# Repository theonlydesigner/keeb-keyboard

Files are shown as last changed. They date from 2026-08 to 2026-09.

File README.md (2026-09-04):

# KYPS75 (because my wallet needed to suffer)

welcome to the KYPS75 repository. this is a scratch-built 75% mechanical keyboard featuring dual rotary encoders and an OLED display [because why have one knob when you can have two?]. i originally designed this after realizing my 60% board was actively sabotaging my daily workflow [turns out arrow keys are actually useful, who knew].

## Features
* 75% exploded layout [so you don't accidentally mash the wrong modifiers while panic-typing]
* dual EC11 rotary encoders [master volume on the left, brush size/timeline scrub on the right]
* 0.91" I2C OLED display [mostly just to show off custom graphics]
* custom 3D-printed enclosure [designed to barely fit the USB-C port]
* QMK/VIA compatible [eventually, whenever i finish fighting the firmware]

## Images of my Build
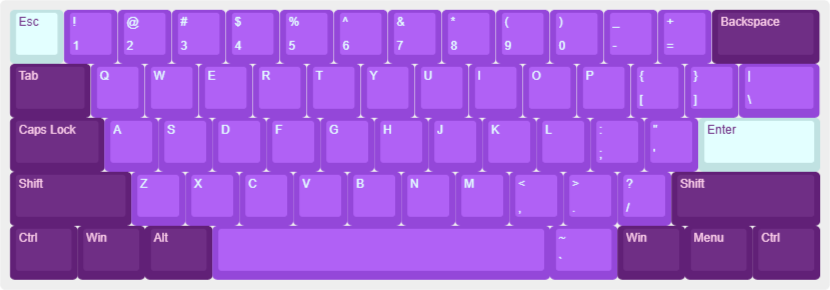
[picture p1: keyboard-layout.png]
layout planning diagram

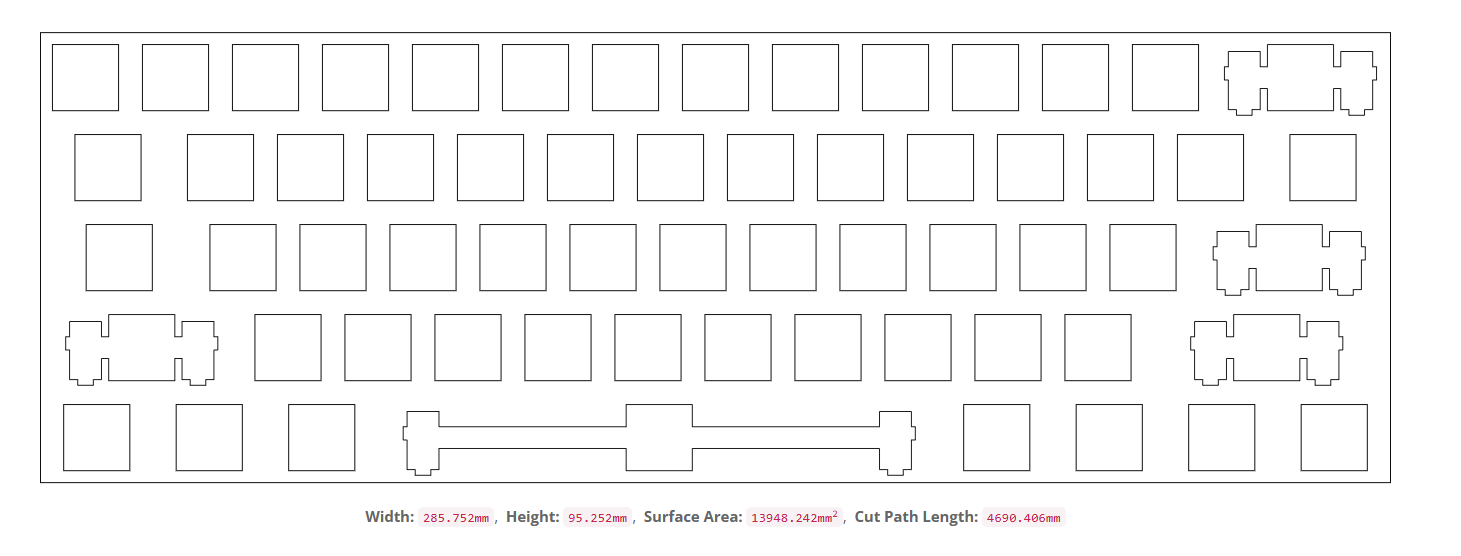
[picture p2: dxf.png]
dxf

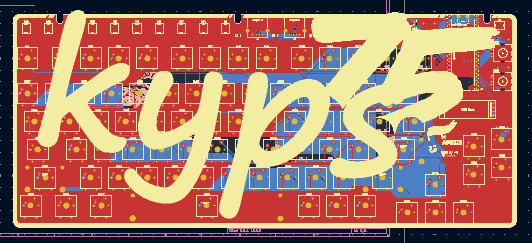
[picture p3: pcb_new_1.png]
pcb_1

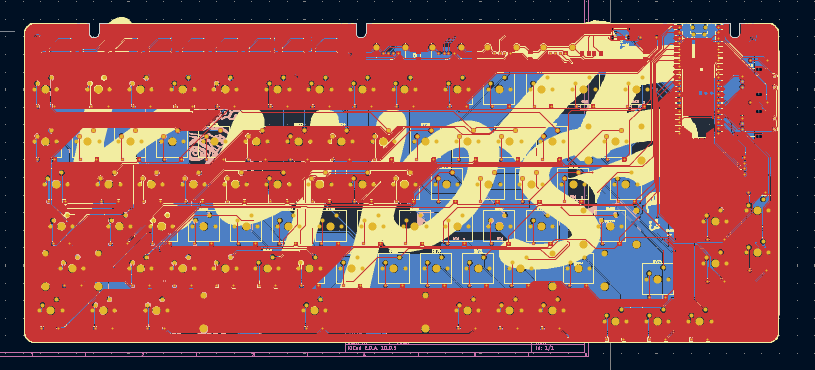
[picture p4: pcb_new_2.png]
pcb_2

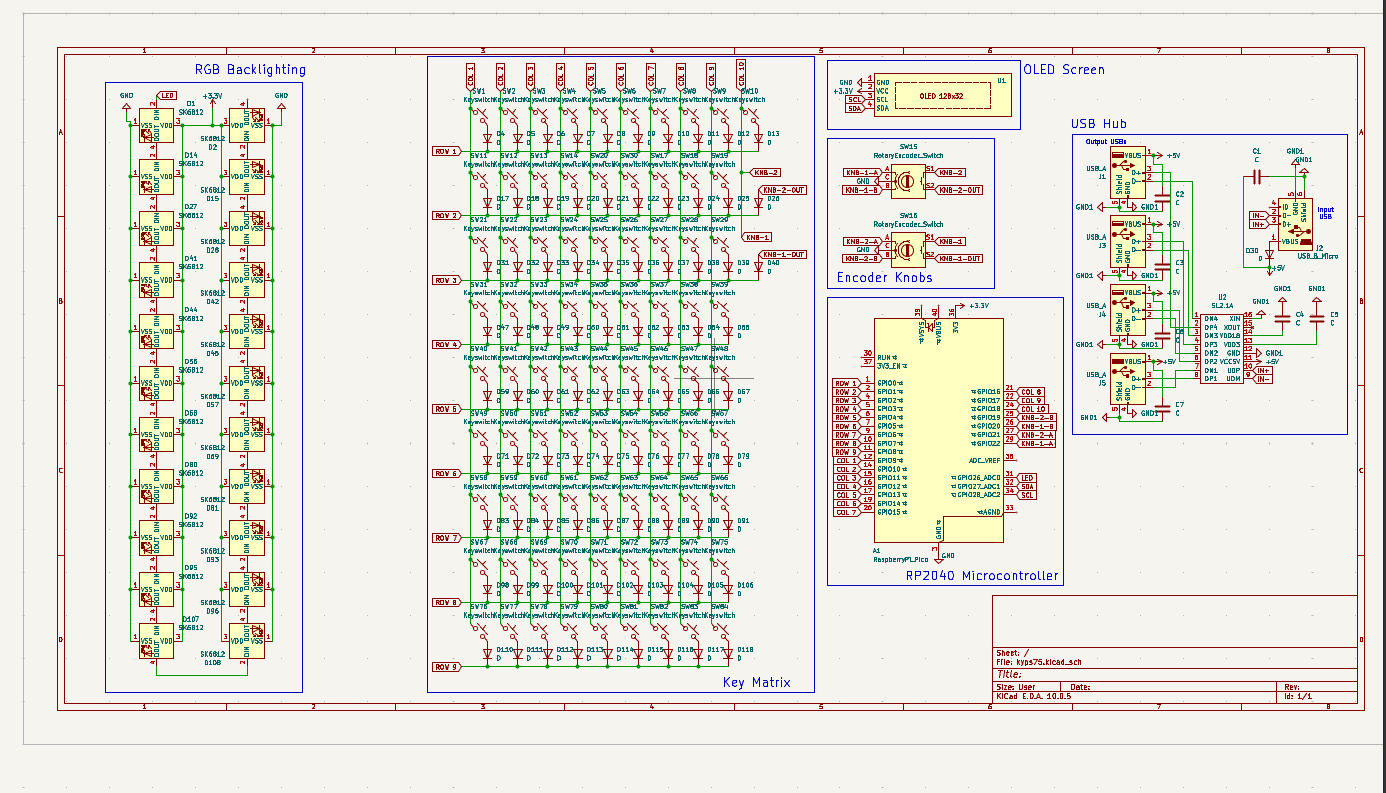
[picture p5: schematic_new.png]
schematic

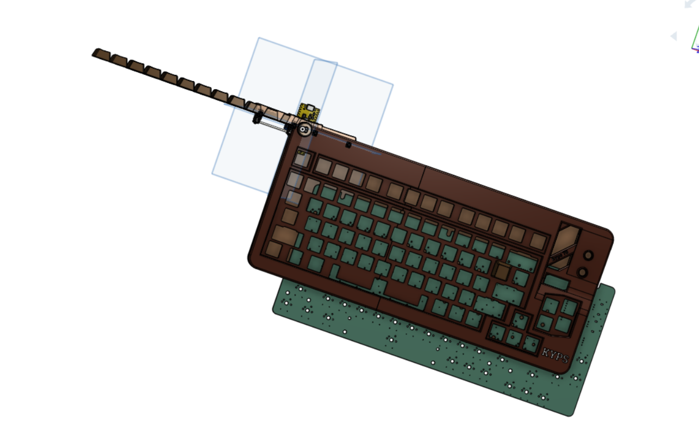
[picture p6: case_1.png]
case_1

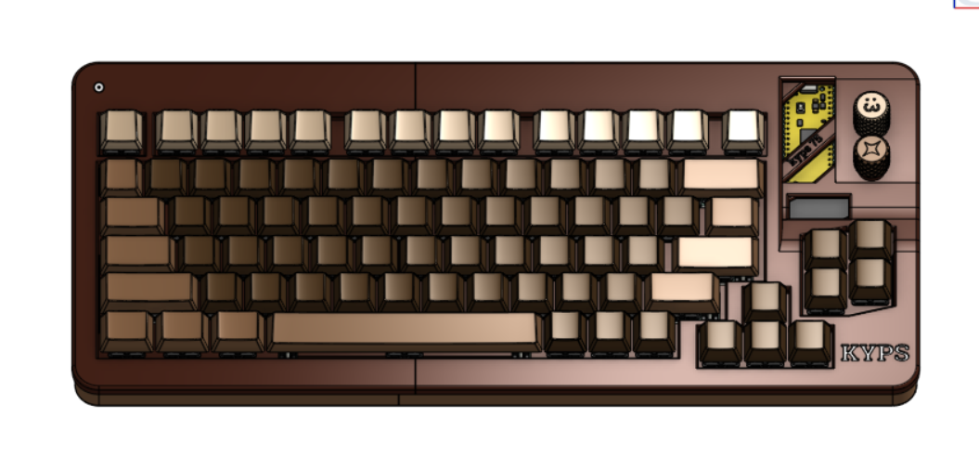
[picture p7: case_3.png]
case_2


## Bill of Materials (BOM)

| Component | Description / Spec | Quantity | Estimated Cost ($) |
| :--- | :--- | :--- | :--- |
| Custom PCB | 75% Layout Scratch-Built PCB | 1 | $15.00 |
| 3D Case | Custom Printed Case (PLA) | 1 | $10.00 |
| Mechanical Switches | MX-Style Mechanical Switches | 82 | $18.00 |
| Rotary Encoders | EC11 Rotary Encoders with Push Switch | 2 | $2.50 |
| OLED Display | 0.91" 128x32 I2C OLED Module | 1 | $3.00 |
| Diodes & SMD | 1N4148 Diodes & SMD Resistors/Caps | 1 Set | $3.50 |
| Keycaps | OEM Profile Keycap Set | 1 | $12.00 |
| **Total** | | | **~$54.00** |

## How to Assemble

1. **PCB SMT Component Soldering:** Solder all surface-mount components (diodes, resistors, capacitors, OLED headers, rotary encoder pins, and controller MCU/sockets) onto the custom PCB.
2. **Switch Placement & Soldering:** Push mechanical switches into the top plate and align switch pins with the PCB socket pads. Solder all switch pins and rotary encoders firmly to the board.
3. **Display & Hardware Installation:** Solder the OLED module onto its header pins and mount the rotary encoder knobs onto the D-shafts.
4. **Case Integration:** Insert the switch/PCB assembly into the 3D-printed bottom housing. Secure it using M2/M3 screws through the mounting tabs.
5. **Keycaps & Finishing:** Press the keycaps onto the switch stems, install rubber feet at the bottom of the case, and plug in the USB-C cable for testing.

(For reviewers- yeah! the assembly is partly written by AI because I had no idea what put into it. but take note,only partly not fully) 

## Known Issues

* **Firmware Pending:** Custom firmware layout is still undergoing final keymapping configuration and key matrix debouncing tweaks. [turns out hardware debouncing is a headache]
* **Tight Case Tolerances:** The 3D-printed case fitment around the USB-C cutout is extremely tight and requires slight filing or precise printer calibration. [sandpaper is your friend]
* **Trace Clearance:** Signal lines near the second rotary encoder required tight routing tolerances; ensure clean soldering to avoid bridging.

## Credits

* **Software & Tools:** [KiCad](https://www.kicad.org/) (PCB & Schematic design), [Keyboard Layout Editor](http://www.keyboard-layout-editor.com/) (Layout concepting), and [SwillKb Plate Builder](http://builder.swillkb.com/) (Plate outline generation).
* **Collaborators:** Special thanks to my two friends for assisting with the 3D enclosure modeling and reviewing the electrical layout logic. [i definitely would have shorted the board and started a fire without them]

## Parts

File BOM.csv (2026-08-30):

Parts | Quantity | Purpose | Price | Total Cost(Including Shipping) | Links
PCB | 1 | Holds components and wires | 82 | 85 | https://cart.jlcpcb.com/quote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
Cherry MX Switches | 82 | Well they press and actually click | 33.05 | 33.05 | https://kprepublic.com/products/cherry-mx-hyperglide-switch-black-switch-for-gaming-mechanical-keyboard-60g-5pin-linear-switch-mx1a-11nw-1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
EC11 Rotatory Encoders | 2 | Turn to change things, macros | 0.97 | 1.6 | https://www.flyrobo.in/ec11-rotary-encoder-with-switch-digital-potentiometer-20mm
SK6812 LEDs 5050 | 22 | To light the keyboard up | 0.87 | 0.87 | https://www.flyrobo.in/5050-red-green-blue-rgb-smd-led?search=SK6812%20LEDs%205050&description=true
0.91 OLED Display | 1 | To display graphics and information | 2.26 | 2.26 | https://www.flyrobo.in/0.91-inch-128-32-oled-display-module-with-i2c-iic-serial-interface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
Raspberry Pi Pico | 1 | Main microcontroller | 7 | 7 | https://jlcpcb.com/parts/componentSearch?searchTxt=Raspberry%20Pi%20Pico
1N4148 Diodes | 85 | Organises rows and columns for microcontroller | Included w/ PCB |  | https://www.flyrobo.in/1n4148-switching-diode-standard-75v-150ma-through-hole
USB A Female Connectors | 5 | Connectors for built in USB-hub | 0.31 | 0.31 | https://www.flyrobo.in/usb-female-90-usb-socket?search=USB%20A%20Female%20Connectors&description=true
Capacitors | 7 | Required for USB hub circuit | 0.1 | 0.1 | https://robu.in/product/grm033r60j104ke19j-murata-electronics-6-3v-100nf-x5r-%c2%b110-0201-multilayer-ceramic-capacitors-mlcc-smd-smt-rohs/
SL2.1A IC | 1 | IC used for USB hub | Included w/ PCB |  | https://jlcpcb.com/partdetail/CoreChips-SL21A/C6798314
6.00u Stabilizers | 1 | Stabilizes the space bar | 21.8 | 21.8 | https://kprepublic.com/products/owlab-stabilizer-v3-pcb-screw-in-stabilizers-for-custom-mechanical-keyboard-kit-2u-6-25u-2x-6-25x-beige-black-pink-purple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
2.00u Stabilizers | 4 | Stabilizes both shift keys, enter, and backspace | Included w/ above
75% Keycaps | 1 Set | Covers keyswitches | 24.15 | 24.15 | https://curiositycaps.in/products/adventurer-1-7mm-thick-pbt-keycaps
Rotary Encoder Knobs | 2 | Covers the encoders | 0 | 0 | 3D print as it is cheaper
#8-32 1/2" Screws | 6 | Assembles the case and plate | 0 | 0 | 3D print as it is cheaper
Micro USB Female Connector | 1 | Input USB for USB hub | 0.03 | 0.03 | https://robu.in/product/micro-usb-type-b-female-5-pin-through-hole-connector/
3D Print(Case, Srews, Knobs) |  | Holds the PCB, Keeps the case together, Provides as a knob to rotate Encoders | 48 | 50.8 | From JLC3DP
 |  |  | Total Cost: | 226.97

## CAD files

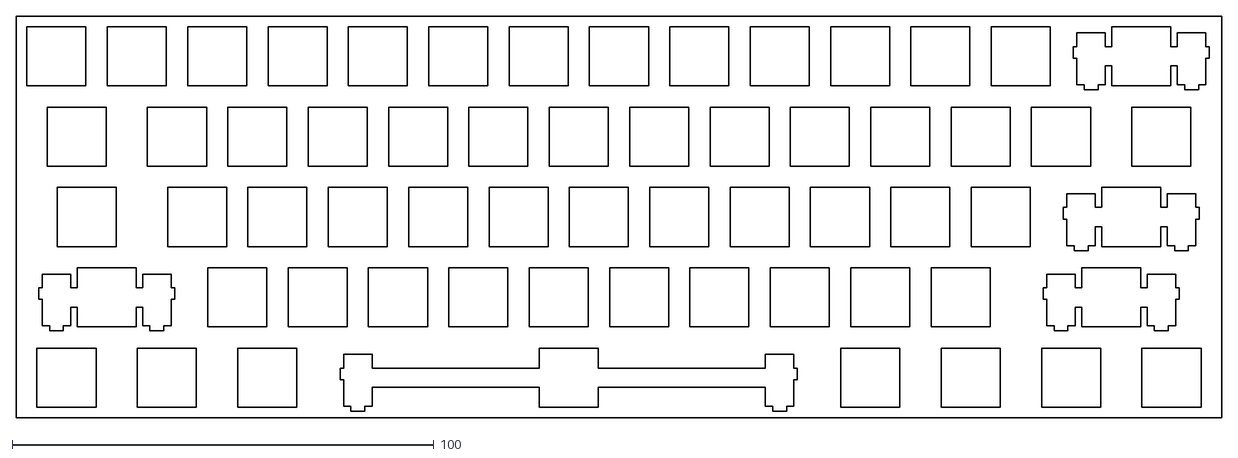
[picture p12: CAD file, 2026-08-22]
d10b4e96a03e68844929e78269e5536b863fd5ac_switch.dxf
285.7 x 95.2

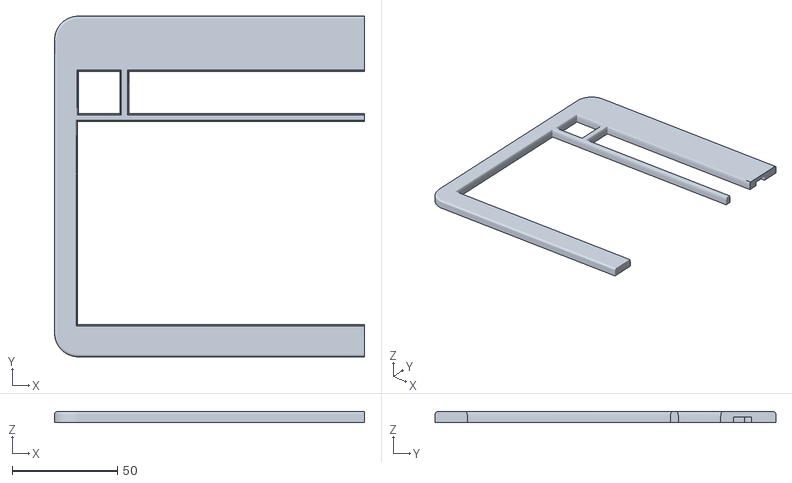
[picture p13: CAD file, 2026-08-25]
Production/STL Files/top shell left.stl
147.2 x 161.8 x 5.08

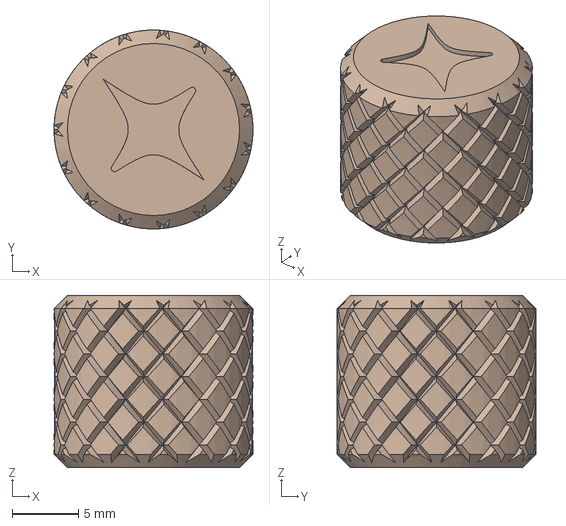
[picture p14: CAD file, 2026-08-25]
Step Files/knob 2.step
15.0 x 15.0 x 13.0 mm

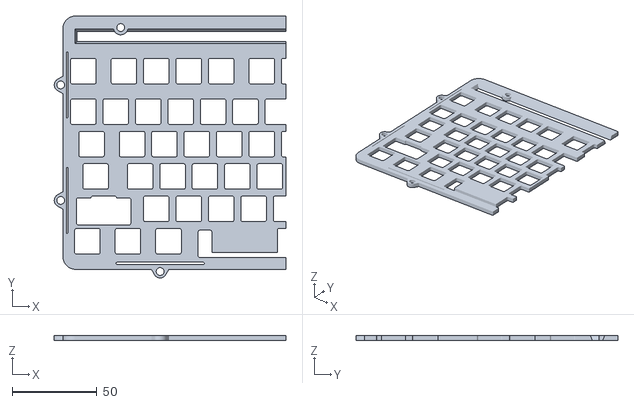
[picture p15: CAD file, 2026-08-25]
Production/STL Files/plate left half.stl
136.2 x 154.2 x 3.18

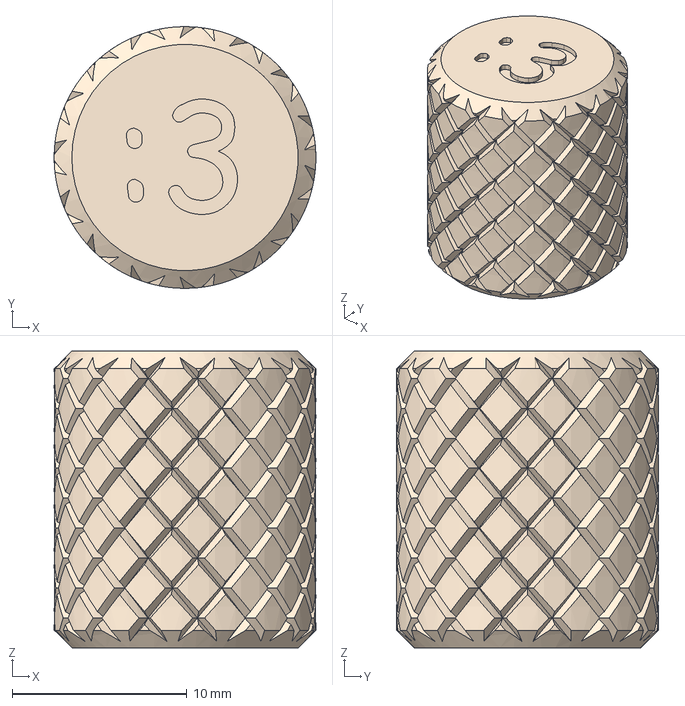
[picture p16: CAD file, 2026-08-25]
Step Files/knob 1.step
15.0 x 15.0 x 17.0 mm

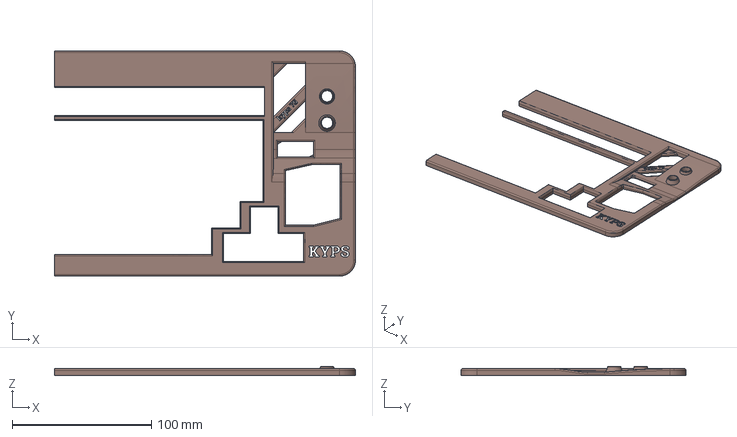
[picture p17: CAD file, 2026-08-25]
Step Files/top shell right.step
216.2 x 161.8 x 6.67 mm

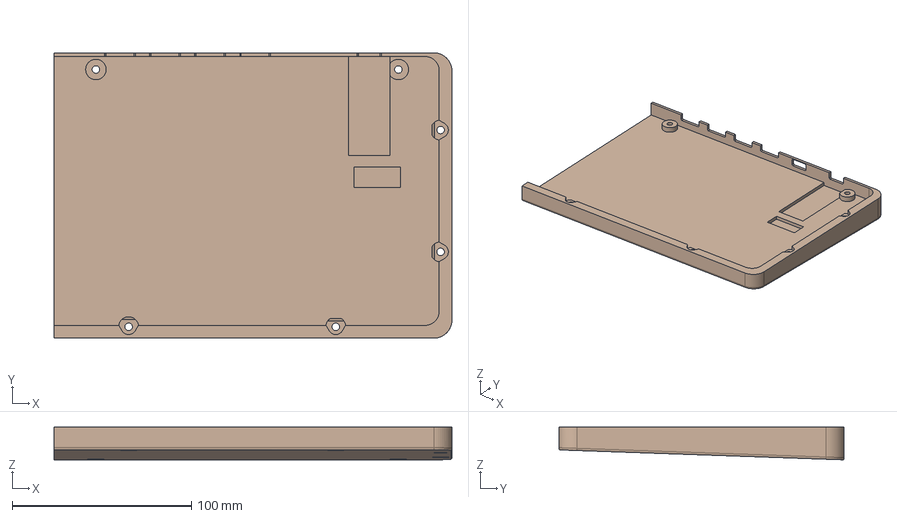
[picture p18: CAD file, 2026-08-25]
Step Files/bottom shell right.step
222.0 x 159.2 x 18.2 mm

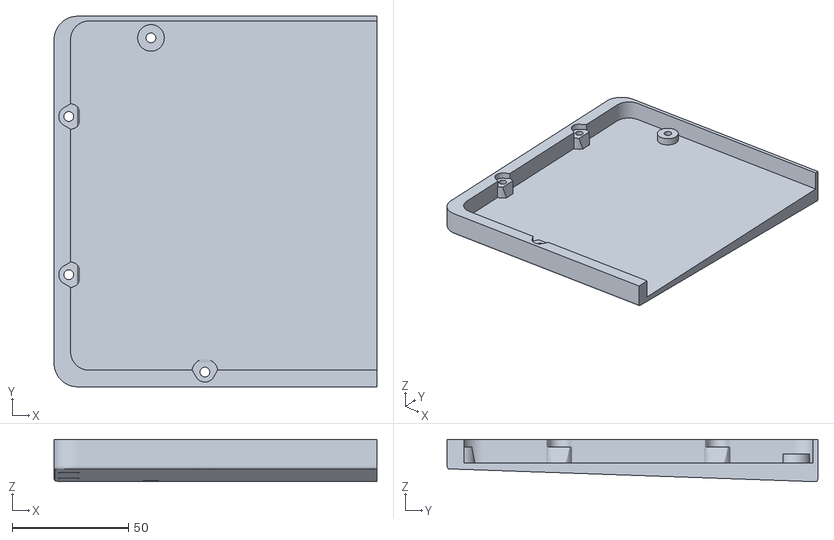
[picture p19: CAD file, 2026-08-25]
Production/STL Files/bottom shell left.stl
138.8 x 159.2 x 18.2

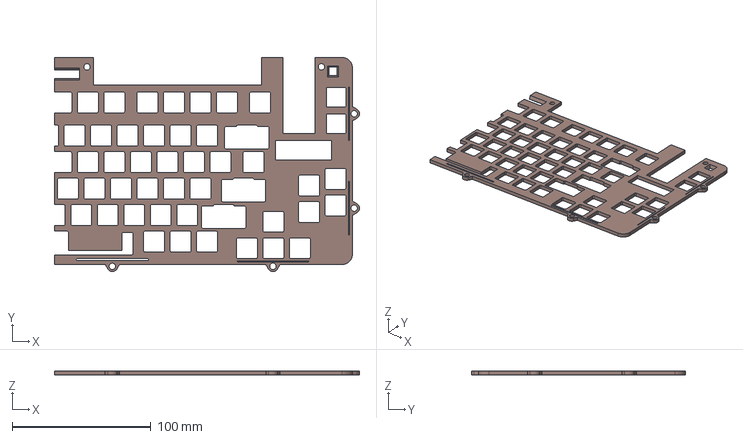
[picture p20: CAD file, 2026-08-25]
Step Files/plate right.step
219.5 x 154.2 x 3.17 mm

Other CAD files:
Step Files/plate left.step
Production/STL Files/knob 2.stl
Production/STL Files/knob 1.stl
Production/STL Files/top shell right.stl
Production/STL Files/bottom shell right.stl
Step Files/top shell left.step
Production/STL Files/plate right.stl
Step Files/bottom shell left.step

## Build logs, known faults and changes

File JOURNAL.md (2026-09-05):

---
title: "kyps75 build journal"
author: "Pratham Rupera"
description: "A comprehensive log of designing a custom 75% mechanical keyboard featuring dual rotary encoders and an OLED display, and all the troubleshooting along the way."
created_at: "2026-08-20"
---

# august 20: deciding on the layout and keymap
So I started the project today originally thinking I'd go with a standard 60% layout. But I quickly realized how much I actually need dedicated arrow keys, navigation keys, and macro controls for when I'm coding and drawing. I decided an exploded 75% layout would work best. I spent hours tweaking the key placements in Keyboard Layout Editor (KLE), trying to figure out the spacing for dual rotary encoders (one for volume, one for brush size and timeline scrolling) and a 0.91" OLED display. I also had to spend a lot of time double-checking the keycap row profiles (R1 to R4) to make sure non-standard sizes, like the 1.75u right shift and 1u bottom-row modifiers, wouldn't cause fitment issues with standard keycap sets.
layout planning diagram
**total time spent: 2 Hours**

# august 21: plate outline and mounting styles
I started off by exporting the KLE raw JSON data into the swillkb plate builder to generate the preliminary DXF vector file for the top plate switch matrix. I had a long debate with myself over the mounting styles. While a gasket mount provides better sound dampening, a sandwich top mount is just far more forgiving for 3D printing and gives better structural rigidity (and saves me a ton of time on designing gasket tabs). I modified the switch cutout corners from crisp right angles to 0.5mm fillets so they accommodate the FDM 3D printer nozzle radii, which should prevent stress fractures around the perimeter. Then I exported the updated CAD files for testing.
plate vector draft
**total time spent: 2 Hours 30 Minutes**

# august 22: doing the schematics and pin mapping
Today I opened KiCad to begin the electrical schematic capture. I selected the MCU board and mapped out all the pin requirements. An 82-key matrix in a 6-row by 15-column layout needs 21 GPIO pins. The dual EC11 rotary encoders need 2 quadrature signals and 1 push-button pin each (6 pins total), and the I2C OLED screen takes 2 pins (SDA/SCL). Running out of pins is a real worry here! I placed the switch components and wired them up with 1N4148 switching diodes across every single node to prevent ghosting and key rollover. I wired up the initial matrix grid, making absolutely sure to verify the diode polarity because having to desolder 82 backwards diodes later would be awful.
kicad schematic matrix
**total time spent: 3 Hours 30 Minutes**

# august 23: wiring up the OLED and encoders
I shifted my focus to integrating the peripheral schematics into the main matrix. First, I wired up the I2C bus line for the 128x32 OLED display and added 4.7kΩ pull-up resistors to both the SDA and SCL lines to ensure clean signal transmission. Then, I placed the footprint logic for the two EC11 rotary encoders. I decided to add RC low-pass filter networks (10kΩ resistors and 10nF capacitors) to hardware-debounce the noisy encoder signals before they even reach the MCU pins. Doing hardware debouncing now should save me from writing annoying software debounce code later. Finally, I consulted two friends to review my logic connections and verify I didn't create any voltage rail shorts lol.
peripheral schematic detail
**total time spent: 3 Hours 30 Minutes**

# august 24: component layout in KiCad
I imported the schematic netlist into KiCad's PCB editor and spent the first two hours just doing manual component arrangement. I placed the 82 switch footprints in a strict 19.05mm x 19.05mm grid alignment so the keycap alignment perfectly matches standard key spacing. I nestled the switch diodes directly underneath each switch footprint to keep the trace lengths as short as possible. Then, I positioned the rotary encoder footprints in the top corners and set the OLED module display window perfectly flush along the upper top bezel. I also made sure to verify the component clear zones so the switch housing clips won't collide with any of the surrounding passive SMD components.
pcb footprint placement
**total time spent: 4 Hours**

# august 25: PCB routing and DRC hell
This was the most intense routing session of the build. I ran traces for the matrix rows and columns on the top layer, while reserving the bottom layer primarily for a solid ground plane. I ran into massive routing congestion near the USB-C cutout and the MCU socket pins. Every time I ran DRC, KiCad suddenly reported clearance errors because my 0.2mm trace widths were overlapping trace-to-pad clearances. I had to manually drop the trace widths down to 0.15mm and reroute the signals around the second rotary encoder footprint. After three full rerouting passes, DRC finally came back with no errors! My eyes definitely hurt after this one.
pcb trace routing completed
**total time spent: 4 Hours 30 Minutes**

# august 27: designing the 3D case
Today I transitioned to 3D CAD modeling to design the main housing. I created a two-piece case design consisting of a top bezel frame and a bottom enclosure tray. I modeled the internal PCB mounting standoffs with pockets for M2 threaded brass inserts. I carefully calculated the wall thickness to a 3.0mm minimum to avoid case flex and resonance, and set an ergonomic typing angle of 6 degrees. I also made sure to add 0.3mm tolerance buffers around all the internal walls. This way, any minor FDM printer expansion won't cause the PCB to bend or bind during installation, which saves me from having to sand PLA later.
3d case cad model
**total time spent: 4 Hours 30 Minutes**

# august 28: finishing the CAD and slicer settings
I finalized the top plate CAD enclosure details today. I designed a recessed window frame for the OLED screen so it can sit flush without actually touching the glass face. Then I created the USB-C breakout port cutout on the rear wall, adding chamfered edges for cable connector clearance so it looks clean. Once that was done, I exported all the components as high-density STL files. I imported the models into PrusaSlicer and configured the print settings: 0.2mm layer height, 25% cubic infill for sound resonance tuning, and organic tree supports for the internal overhangs. The project is finally ready for test printing and firmware configuration! :D
slicer preview and render
**total time spent: 3 Hours**

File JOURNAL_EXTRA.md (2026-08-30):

---
title: "kyps75 build journal"
author: "theonlydesigner(or perhaps Pratham Rupera)"
description: "a comprehensive log of designing a custom 75% mechanical keyboard featuring dual rotary encoders and an oled display [and me losing my sanity]."
created_at: "2026-08-20"
---

# august 20: ergonomic evaluation & keymap architecture
started the project originally thinking about a standard 60% layout, but quickly realized how much i miss dedicated arrow keys, navigation keys, and specialized macro controls during late-night coding and drawing sessions. [turns out i'm not a masochist and actually like being productive]. settled on an exploded 75% layout. spent hours tweaking key placements on keyboard layout editor (KLE), evaluating spacing for dual rotary encoders [one for master volume, one for brush size/timeline scrolling because scrolling with a mouse is for peasants] and a dedicated 0.91" oled display. spent time double-checking keycap row profiles (r1 to r4) to ensure non-standard key sizes like the short 1.75u right shift and 1u bottom-row modifiers wouldn't cause fitment issues with off-the-shelf keycap sets.
layout planning diagram
**total time spent: 2.0 hours**

# august 21: cad plate outline & mounting strategy
exported the KLE raw json data into swillkb plate builder to generate the preliminary dxf vector file for the top plate switch matrix. had a long design debate with myself over mounting styles: gasket mount, top mount, or integrated plate. while gasket mount provides better sound dampening, sandwich top mounting is far more forgiving for 3d printing and structural rigidity [and let's be real, i'm not spending 10 extra hours designing gasket tabs]. modified the switch cutout corners from crisp right angles to 0.5mm fillets to accommodate fdm 3d printer nozzle radii and prevent stress fractures around the perimeter. exported updated cad files for testing.
plate vector draft
**total time spent: 2.5 hours**

# august 22: schematic initialization & mcu pin allocation
opened kicad to begin electrical schematic capture. selected the micro-controller unit (mcu) board, mapping out total pin requirements. an 82-key matrix configured in a 6-row by 15-column layout requires 21 gpio pins. the dual ec11 rotary encoders require 2 quadrature signals and 1 push-button pin each (6 pins total), and the i2c oled screen takes 2 pins (sda/scl). [math is hard but running out of pins is harder]. placed the switch components along with 1n4148 switching diodes across every single node to prevent ghosting and key rollover issues. wired up the initial matrix grid, carefully verifying diode polarity [because desoldering 82 backwards diodes sounds like my personal hell].
kicad schematic matrix
**total time spent: 3.5 hours**

# august 23: peripheral wiring & bus pulldown logic
shifted focus to integrating the peripheral schematics into the main matrix schematic. wired up the i2c bus line for the 128x32 oled display, adding 4.7kΩ pull-up resistors to both sda and scl lines to ensure clean signal transmission and prevent bus locks. placed the footprint logic for the two ec11 rotary encoders, adding rc low-pass filter networks (10kΩ resistors and 10nf capacitors) to hardware-debounce the noisy encoder signals before reaching the mcu pins. [turns out hardware debouncing saves you from writing terrible software debounce code later]. consulted two friends to review the logic connections and verify i didn't create any voltage rail shorts [they basically saved me from starting a small desk fire].
peripheral schematic detail
**total time spent: 3.5 hours**

# august 24: footprint layout & matrix routing strategy
imported the schematic netlist into kicad pcbnew. spent the first two hours doing manual component arrangement [which is just digital tetris for nerds]. placed the 82 switch footprints in a strict 19.05mm x 19.05mm grid alignment to ensure keycap alignment matches standard key spacing. nestled the switch diodes directly underneath each switch footprint to keep trace lengths short. positioned the rotary encoder footprints in the top corners and set the oled module display window flush along the upper top bezel. verified component clear zones so switch housing clips won't collide with surrounding passive smd components.
pcb footprint placement
**total time spent: 4.0 hours**

# august 25: trace routing & clearance drc failures
the most intense routing session of the build. ran traces for the matrix rows and columns on the top layer while reserving the bottom layer primarily for a solid ground plane. ran into massive routing congestion near the usb-c cutout and mcu socket pins. kept triggering automated design rule check (drc) clearance errors due to 0.2mm trace widths overlapping trace-to-pad clearances. [drc errors are literally the bane of my existence]. had to manually drop trace widths down to 0.15mm and reroute signals around the second rotary encoder footprint. cleared all drc errors after three full rerouting passes. my eyes hurt.
pcb trace routing completed
**total time spent: 4.5 hours**

# august 27: 3d case modeling & internal standoffs
transitioned to 3d cad modeling to design the main housing. created a two-piece case design consisting of a top bezel frame and a bottom enclosure tray. modeled internal pcb mounting standoffs with m2 threaded brass insert pockets. carefully calculated wall thickness (3.0mm minimum) to avoid case flex and resonance. set an ergonomic typing angle of 6 degrees. added 0.3mm tolerance buffers around all internal walls so minor fdm printer expansion won't cause the pcb to bend or bind during installation [because 3d printers lie about their tolerances and i refuse to sand PLA for 3 hours].
3d case cad model
**total time spent: 4.5 hours**

# august 28: oled bezel, port cutouts & slicer setup
finalized the top plate cad enclosure details. designed a recessed window frame for the oled screen to sit flush without touching the glass face. created the usb-c breakout port cutout on the rear wall, adding chamfered edges for cable connector clearance [mostly so it doesn't look like i gnawed the hole out with my teeth]. exported all components as high-density stl files. imported the models into prusaslicer to configure print settings: 0.2mm layer height, 25% cubic infill for sound resonance tuning, and organic tree supports for the internal overhangs. ready for test printing and final firmware configuration.
slicer preview and render
**total time spent: 3.0 hours**

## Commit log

2026-08-22 Added layout and blueprint
    [d10b4e96a03e68844929e78269e5536b863fd5ac_switch.dxf]
2026-08-25 Added the latest files
    [bottom shell left.step, bottom shell left.stl, bottom shell right.step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]
2026-08-25 Update README with new build journal entry
    Added detailed entry about completing the PCB and 3D case, including time spent, challenges faced, and visual progress.
2026-08-25 Update images in README for visual progress
    Removed old images and added new PCB and schematic images.
2026-08-25 Replace 3D case images with updated versions
    Updated images in the README to reflect new case designs.
2026-08-26 Added BOM
    [BOM.xlsx]
2026-08-26 Add entry for completed BOM in README
2026-08-26 Correct time spent entry in JOURNAL.md
    Updated time spent on PCB and 3D case entry.
2026-08-30 Added BOM.csv
    [BOM.csv]
2026-08-30 Revise README with detailed project information
    Expanded project description, added features, BOM, assembly instructions, known issues, and credits.
